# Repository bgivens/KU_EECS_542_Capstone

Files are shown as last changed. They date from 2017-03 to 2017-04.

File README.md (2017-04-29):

# Folders
### 3D_Structural_Files:
This folder contains the 3D .stl files used to print out structural parts needed for this project, including the spraycan mount, the metal detector mount, the controller, as well as the servo mounts.

### Adafruit_Motor_Shield_V2_Library-master:
This is the Arduino library used with the motor shield that is used to control the rover motors. This library is used by Rover_Code.ino.

### metal_detector:
This folder contains the .ino Arduino file used to program the Arduino that handles all metal detector functionality.

### rc_test and rc_test_variables:
These files are test files used to test code ideas for rover control. While some of the code used in these files is present in other .ino, these files themselves are not used at all in the final product.

### Rover_Code:
This folder contains the .ino file used to program the Arduino that controls the rover.

### UNO_Controller:
This folder contains the .ino file used to program the Arduino used to control the rover.

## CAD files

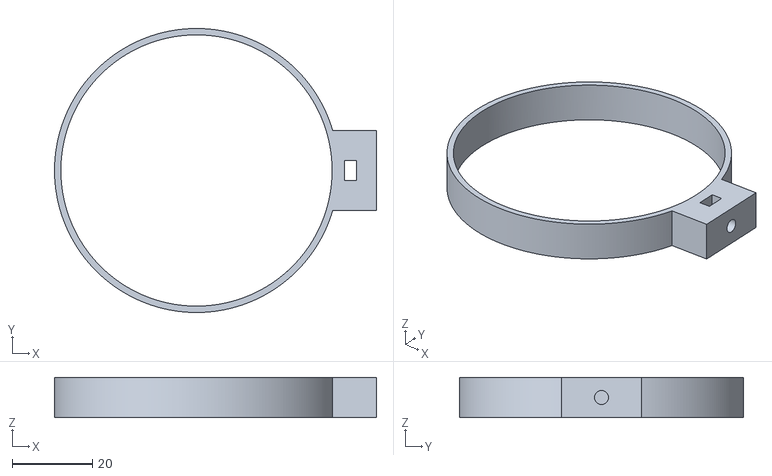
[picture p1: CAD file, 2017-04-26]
3D_Structural_Files/spraycan_mount.stl
80.5 x 71.0 x 10.0

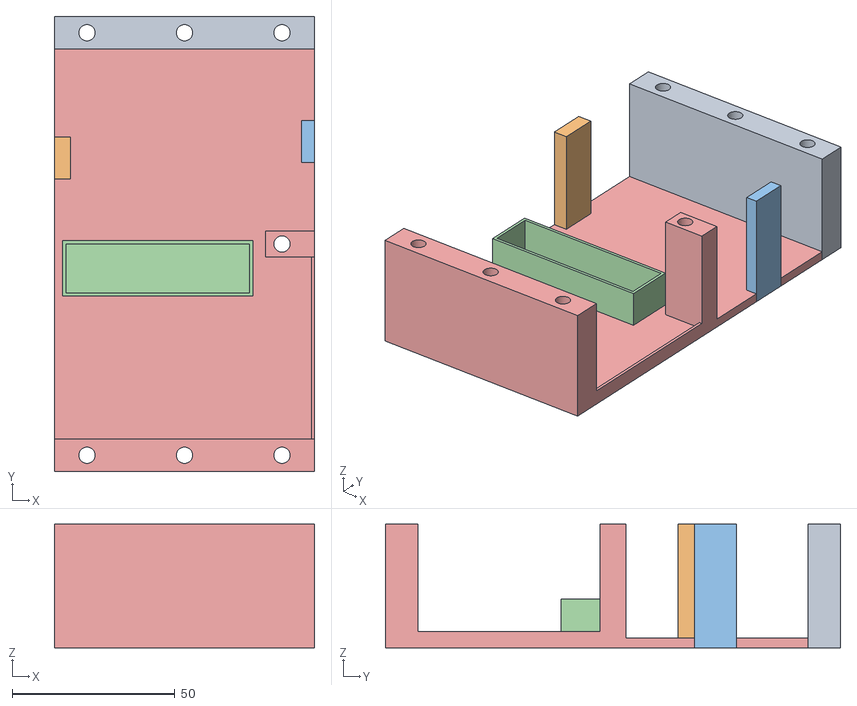
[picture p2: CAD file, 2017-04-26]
3D_Structural_Files/controller_bottom.stl
80.0 x 140.0 x 38.0

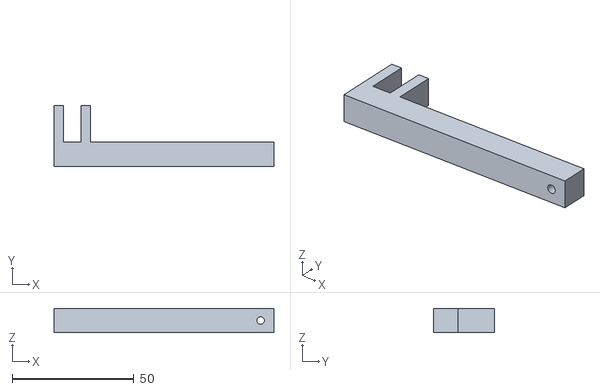
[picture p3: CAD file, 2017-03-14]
3D_Structural_Files/metal_detector_mount.stl
90.5 x 25.0 x 10.0

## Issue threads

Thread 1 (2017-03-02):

Add control signal

Kurrikov, 2017-03-02:
To support having the zero button for the metal detector on the remote control, a signal needs to be defined to communicate from the controller to the rover that the metal detector should be zeroed. Code that reads this button should be moved to the controller.

bgivens, 2017-03-09:
It appears that this issue has been addressed.

Closed 2017-03-09.

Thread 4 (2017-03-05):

Contribute to README

Kurrikov, 2017-03-05:
Explain what the purpose of the repository as a whole, what each file does, and how the hardware is set up.

bgivens, 2017-04-26:
Descriptions of each folder in the repository have been added. We should still add a description of the project as a whole to the README file. This should include a description of each of the components, as well as how they work together. We likely want a circuit diagram of the Colpitt's Oscillator somewhere as well.

Closed 2018-10-23.

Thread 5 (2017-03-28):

Push Libraries

dhauptman, 2017-03-28:
Push the libraries that we use for the Arduino code.

bgivens, 2017-04-26:
Motor shield library has been added

Closed 2017-04-26.

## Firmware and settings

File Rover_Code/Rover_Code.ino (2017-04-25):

//Motor Imports & Variables
#include <Wire.h>
#include <Adafruit_MotorShield.h>
//#include <SoftwareSerial.h>
#include <Servo.h>
// #include "utility/Adafruit_MS_PWMServoDriver.h"

#define ENABLE_SPRAY 0
#define BAUDRATE 9600

// Pin definitions
#define SPRAYCAN_PIN 7
#define FOUND_PIN 9
#define ZERO_PIN 8
#define ERROR_HIGH 4
#define ERROR_LOW 3
#define SPRAY_INTERVAL 5


// Initialize motor shield
Adafruit_MotorShield AFMS = Adafruit_MotorShield();
Adafruit_DCMotor* right_motor = AFMS.getMotor(1);
Adafruit_DCMotor* left_motor = AFMS.getMotor(2);

// Variables
Servo spraycan;
unsigned int spray_counter = 10;
int zero_value = 0;
int found = 0;
int left_motor_val = 255;
int right_motor_val = 255;
int new_left_motor = 255;
int new_right_motor = 255;
char buffer[20]; // Buffer for sending/receiving strings


void setup() {
  pinMode(SPRAYCAN_PIN, OUTPUT);

  AFMS.begin();  // create with the default frequency 1.6KHz
  right_motor->run(RELEASE);
  left_motor->run(RELEASE);
  spraycan.attach(SPRAYCAN_PIN);
  spraycan.write(180);

  // Initialize hardware serial
  Serial.begin(BAUDRATE);
  // Wait for serial port to connect. Needed for hardware serial
  while (!Serial) ;
  
  pinMode(FOUND_PIN, INPUT_PULLUP);
  pinMode(ZERO_PIN, OUTPUT);
  
  pinMode(ERROR_HIGH, OUTPUT);
  pinMode(ERROR_LOW, OUTPUT);
  digitalWrite(ERROR_HIGH, LOW);
  digitalWrite(ERROR_LOW, LOW);  
}


void loop() {
  // If data has been received on the xbee
  if (Serial.available()) {
    // Read from serial and parse incoming data
    new_left_motor = Serial.parseInt();
    new_right_motor = Serial.parseInt();
    zero_value = Serial.parseInt();
    
    // Error check input
    if (new_left_motor != 0 && new_right_motor != 0 && (zero_value == 0 || zero_value == 1)) {
      left_motor_val = new_left_motor;
      right_motor_val = new_right_motor;
      digitalWrite(ERROR_HIGH, LOW);
    } else {
      // Bad input from xbee (you should reset rover and controller Unos)
      digitalWrite(ERROR_HIGH, HIGH);
      // Stop rover in event of an error
      left_motor_val = 255;
      right_motor_val = 255;
      while(Serial.available())
      {
      	int clear_buffer = Serial.read();
      }
    }
    
    // Adjust the speed and direction of the right and left motors
    controlMotor(right_motor_val, 1);
    controlMotor(left_motor_val, 2);

    // Pass zeroing instructions to the metal detector Uno
    // but only send instructions when a value is received from the controller
    digitalWrite(ZERO_PIN, !zero_value);
    
    // Send metal detector found status to controller
    found = !digitalRead(FOUND_PIN);
    Serial.println(found);
    
    #if ENABLE_SPRAY
    if (found) {
      spraycan.write(100);
      spray_counter = 0;
    }
    
    
    if (spray_counter < SPRAY_INTERVAL) {
      ++spray_counter;
    } else {
      spraycan.write(180);
    }
    #endif
  }
}


// Control the speed and direction of a motor
// \param motor_val the raw motor value received from controller
// \param motor which motor to control
// 1 corresponds to the right motor, 2 corresponds to the left motor
void controlMotor(int motor_val, int motor) {
  // Motor values are received as [0, 510 values]
  motor_val = motor_val - 255;

  if (motor_val > 20) {
    if (motor == 1) {
      right_motor->run(FORWARD);
      right_motor->setSpeed(motor_val);
    } else {
      left_motor->run(FORWARD);
      left_motor->setSpeed(motor_val);
    }
  } else if (motor_val < -20) {
    if (motor == 1) {
      right_motor->run(BACKWARD);
      right_motor->setSpeed((-1)*motor_val);
    } else {
      left_motor->run(BACKWARD);
      left_motor->setSpeed((-1)*motor_val);
    }
  } else {
    if (motor == 1) {
      right_motor->run(RELEASE);
    } else {
      left_motor->run(RELEASE);
    }
  }
}

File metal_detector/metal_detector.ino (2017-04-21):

/*
 * Copyright (c) 2016 Evan Kale
 * Media: @EvanKale91
 * Email: EvanKale91@gmail.com
 * Website: www.ISeeDeadPixel.com
 *          www.evankale.blogspot.ca
 *          www.youtube.com/EvanKale91
 *
 * This file is part of ArduinoMetalDetector.
 *
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
 * You should have received a copy of the GNU General Public License
 * along with this program.  If not, see <http://www.gnu.org/licenses/>.
 */
 /*
 * Modified by: Daniel Norman
 */

#define SERIAL_DEBUG 0

// Number of cycles from external counter needed to generate a signal event
#define CYCLES_PER_SIGNAL 5000

// Base tone frequency (speaker)
#define BASE_TONE_FREQUENCY 280

// Frequency delta threshold for fancy spinner to trigger
#define MARKING_THRESHOLD 400

// Pin definitions
#define FOUND_PIN 9
#define LED_PIN 13
#define ZERO_PIN 8
#define BAUDRATE 9600


float sensitivity = 10.0;

unsigned long lastSignalTime = 0;
unsigned long signalTimeDelta = 0;

boolean firstSignal = true;
unsigned long storedTimeDelta = 0;

// This signal is called whenever OCR1A reaches 0
// (Note: OCR1A is decremented on every external clock cycle)
SIGNAL(TIMER1_COMPA_vect) {
  unsigned long currentTime = micros();
  signalTimeDelta =  currentTime - lastSignalTime;
  lastSignalTime = currentTime;

  if (firstSignal) {
    firstSignal = false;
  } else if (storedTimeDelta == 0) {
    storedTimeDelta = signalTimeDelta;
  }

  // Reset OCR1A
  OCR1A += CYCLES_PER_SIGNAL;
}


void setup() {
  // Set WGM(Waveform Generation Mode) to 0 (Normal)
  TCCR1A = 0b00000000;

  // Set CSS(Clock Speed Selection) to 0b111 (External clock source on T0 pin
  // (ie, pin 5 on UNO). Clock on rising edge.)
  TCCR1B = 0b00000111;

  // Enable timer compare interrupt A (ie, SIGNAL(TIMER1_COMPA_VECT))
  TIMSK1 |= (1 << OCIE1A);

  // Set OCR1A (timer A counter) to 1 to trigger interrupt on next cycle
  OCR1A = 1;

  pinMode(FOUND_PIN, OUTPUT);
  pinMode(LED_PIN, OUTPUT);
  pinMode(ZERO_PIN, INPUT_PULLUP);


  #if SERIAL_DEBUG
  Serial.begin(9600);
  Serial.println("Beginning Metal Detector");
  #endif
}

void loop() {
  //float sensitivity = mapFloat(analogRead(SENSITIVITY_POT_APIN), 0, 1023, 0.5, 10.0);
  
  int storedTimeDeltaDifference = (storedTimeDelta - signalTimeDelta) * sensitivity;
  // tone(SPEAKER_PIN, BASE_TONE_FREQUENCY + storedTimeDeltaDifference);

  #if SERIAL_DEBUG
  //Serial.println(storedTimeDeltaDifference);
  #endif
  
  // Determine if a mine is detected and send found status back to rover
  if (storedTimeDeltaDifference > MARKING_THRESHOLD) {
    // Currently detecting a mine
    #if SERIAL_DEBUG
    Serial.println(0);
    #endif
    digitalWrite(FOUND_PIN, LOW);
    digitalWrite(LED_PIN, HIGH);
  } else {
    // Not detecting a mine
    #if SERIAL_DEBUG
    Serial.println(1);
    #endif
    digitalWrite(FOUND_PIN, HIGH);
    digitalWrite(LED_PIN, LOW);
  }

  // Reset metal detector when instructed
  if (digitalRead(ZERO_PIN) == LOW) {
    storedTimeDelta = 0;
//    Serial.println("zero");
    // digitalWrite(RESET_BTN_OUTPUT, HIGH);
  }
  // digitalWrite(RESET_BTN_OUTPUT, LOW);
}

float mapFloat(int input, int inMin, int inMax, float outMin, float outMax) {
  float scale = (float)(input - inMin) / (inMax - inMin);
  return ((outMax - outMin) * scale) + outMin;
}

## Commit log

2017-02-20 Add Arduino Uno controller code
2017-03-02 Add files via upload
    Add spray can mount files
    [spraycan_mount.stl]
2017-03-03 Added Reset button to controller, added sensitivity potentiometer
    Still have errors with metal detector. It blinks periodically for no
    reason. Probably a timing issue.
    [Rover_Code.ino, UNO_Controller.ino]
2017-03-05 Added method controlMotor to simplify motor interaction
2017-03-09 Tested servos
2017-03-09 Removed software servo stuff, considering two microcontroller option
2017-03-10 Add metal detector mount files
    [metal_detector_mount.stl]
2017-03-14 Modify mounting files
    [metal_detector_mount.stl, spraycan_mount.stl]
2017-03-15 Cleanup and spraycan work
    Removed more unnecessary code and made preliminary work on the servo to control the marking spraycan
2017-03-31 Modify spray can mount files
    [spraycan_mount.stl]
2017-04-08 Minor bug fixes and formatting
    [Rover_Code.ino, UNO_Controller.ino, metal_detector.ino]
2017-04-18 Modified rover to use parallel, digital wires to communicate found and zero instructions.
2017-04-20 Servo Code
2017-04-20 Moved rover to hardware serial and optimized other code to reduce serial problems.
    [Rover_Code.ino, UNO_Controller.ino, metal_detector.ino]
2017-04-25 Add functionality to rover error checking to clear serial buffer upon detection of an error
    [Rover_Code.ino]
2017-04-26 Change EECS542 filename to 3D_Structural_Files to better reflect purpose of files in this folder
    [controller_bottom.stl, metal_detector_mount.stl, spraycan_mount.stl]
2017-04-26 Cleanup file directory
    [metal_detector_mount.stl, spraycan_mount.stl]
2017-04-29 Switching to proper markdown for readme

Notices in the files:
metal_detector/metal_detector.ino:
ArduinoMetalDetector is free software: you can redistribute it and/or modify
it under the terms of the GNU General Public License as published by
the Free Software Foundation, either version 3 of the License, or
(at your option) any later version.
